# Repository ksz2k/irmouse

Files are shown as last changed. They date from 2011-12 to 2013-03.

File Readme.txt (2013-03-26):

Readme for IRMouse - infra red controlled USB mouse device (HID class)

https://github.com/ksz2k/irmouse

	ABOUT IRMouse

IRMouse is an USB mouse controlled by ir remote..
It receives packets from remote, decodes, and (if ir code matching) sends 
reports to PC via USB.. Reports are as in standard USB mouse, so there is no
need for additional programs/drivers on PC side, everything is done in IRMouse
and system recognizes it as standard USB mouse..

It is built on two ATtiny2313 uC's connected via USART..
I've tried to make it on one ATmega8, but there was too much interrupts at
the same time (from USB host and from IR), and one AVR couldn't make it work,
after few packets received from remote, the device was disapeared from USB bus.
If you're more interested on this problem, see
http://forums.obdev.at/viewtopic.php?t=243  (-;

	HARDWARE / FIRMWARE MISC INFORMATION

For now firmware decodes only SPACE_ENCODED standards of IR transmittion,
if you'll add your own, let me know..

The USB ATtiny is clocked by external 12MHz crystal, IR ATtiny by internal 
8MHz clock.

Aditionally I've used some strange Sanyo remote, that for every ir packet was 
sending different code, and only first was always the same, so there is an 
option for check only first code, and send reports without later ir code 
recheck. This happens when JP1 is closed to GND..

	PRE-BUILD CONFIGURATION

You probably want to change the remote codes and timings, I'm using separate .h
file for every remote, in remotes/ there is remote_template.h as template, just
rename it to yours remote and define it's timings and codes. Then change
REMOTE in Makefile and add #ifdef in main-ir.c

If ZERO_TEST in main-ir.c is defined, device comparing the TZEROH time, else 
TONEH. You may need to compare other times, you can change it in main-ir.c in 
main() and makeReport() functions..

In usbconfig.h you can change the device/vendor names, but be careful, because
the compilers' output file for USB is 2036B size, so it's almost full..

USART speed is 38400bd, it can be changed in defines.h

	BUILD INFORMATION

The firmware code was written for and tested with avr-gcc (avr-libc 1.4), 
compiled on Linux, but with WinAVR on Windows should work fine too.. For 
programming the AVR's I've used great AVRDUDE.. See Makefile for info and some
config options..

To build firmware, just 'make' and there should be two .hex files.. 
'make flashir' flashes the IR target, and 'make flashusb' - USB target. 
Also you can set fuses of both targets ('make fuseir' and 'make fuseusb'). 
For more details see Makefile's comments..

	LICENSE

The project is built with AVR USB driver by Objective Development, which is
published under a proprietary Open Source license. To conform with this
license, IRMouse is distributed under the same license conditions. See the
file usbdrv/License.txt for details. 

	FILES IN THE DISTRIBUTION

Readme.txt ............. The file you are currently reading
usbdrv ................. AVR USB driver by Objective Development
usbdrv/License.txt ..... Public license for AVR USB driver and IRMouse
circuit ................ Circuit diagram in PNG and EAGLE format
remotes ................ Different remotes header files
main-ir.c .............. Main file for IR ATtiny
main-usb.c ............. Main file for USB ATtiny
usbconfig.h ............ USB configuration file
defines.h .............. Some definitions for both IR and USB uC's

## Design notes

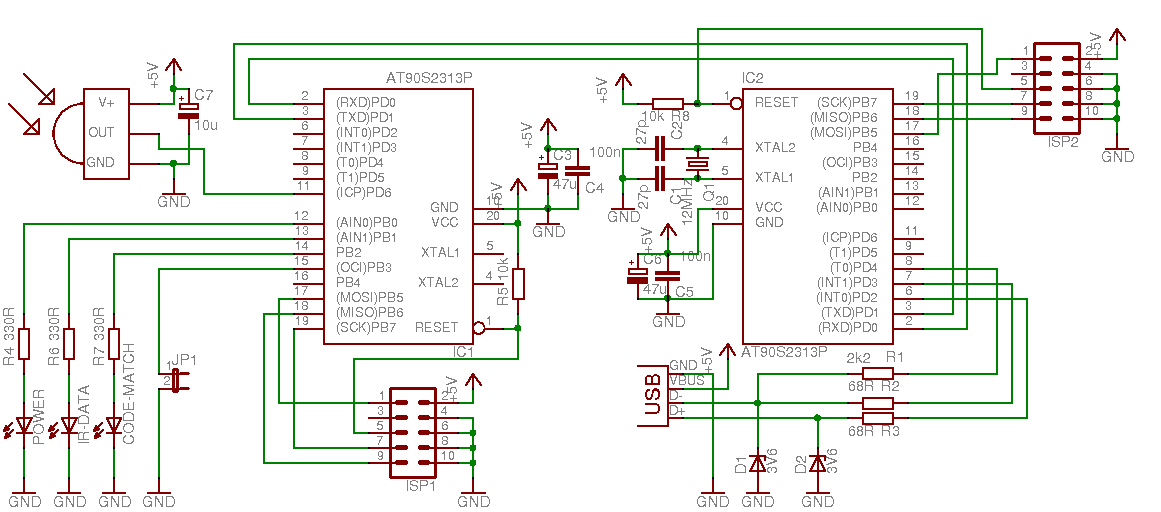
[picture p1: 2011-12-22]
circuit/irmouse.png

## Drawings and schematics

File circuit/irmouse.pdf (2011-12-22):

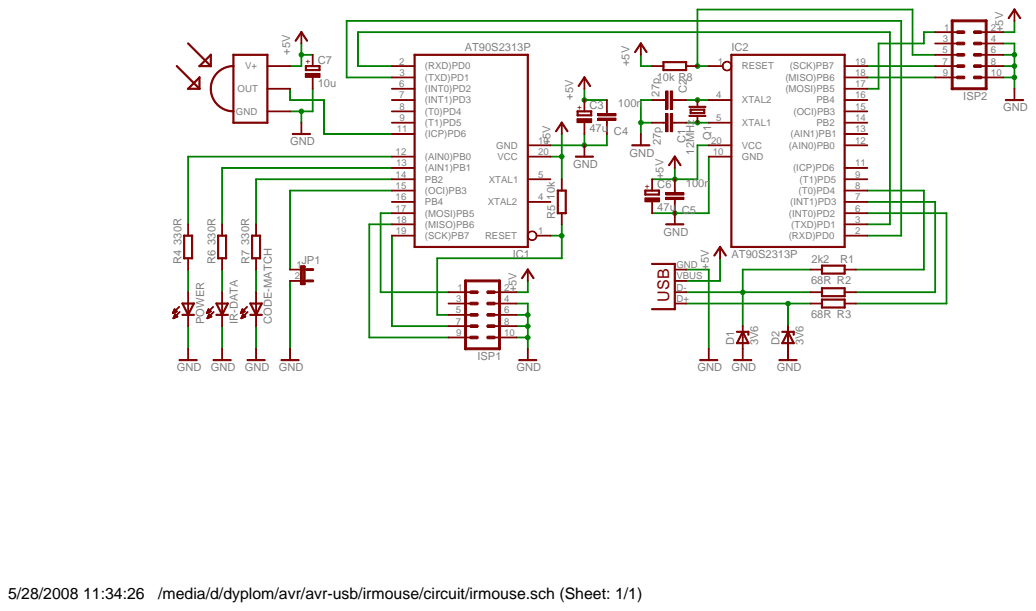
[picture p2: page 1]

5/28/2008 11:34:26 /media/d/dyplom/avr/avr-usb/irmouse/circuit/irmouse.sch (Sheet: 1/1)

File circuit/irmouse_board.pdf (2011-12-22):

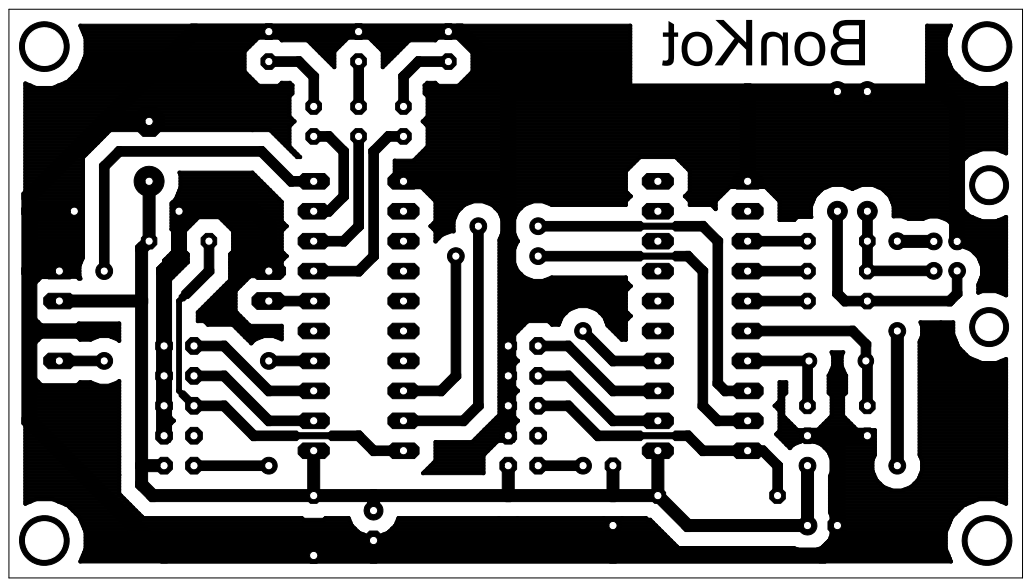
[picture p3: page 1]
t oKnoB

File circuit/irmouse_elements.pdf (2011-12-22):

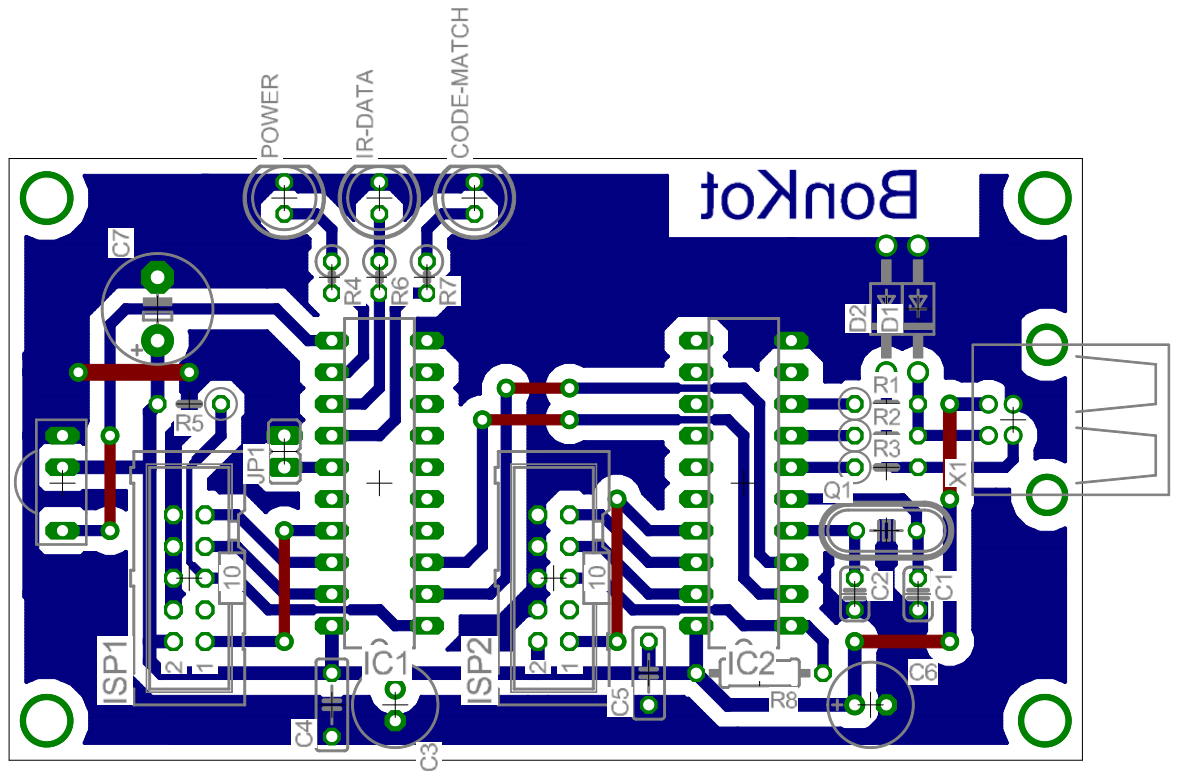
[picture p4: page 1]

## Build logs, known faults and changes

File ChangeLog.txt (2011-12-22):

2010-08-04 :: v00.21
	
	* board project added (found on the net)

2007-03-01 :: v00.20

	* remote timings and codes moved to separate files in remotes dir
	* no precompiled hex files in distribution
	* infos in Readme.txt added

2007-02-16 :: v00.10

	* first release with two tinys2313 connected via USART
	  It just works, no conflicts with host, no dmesg's errors, cursor moves :D
	
2006-01-10 - 2007-02-12 :: v00.01 - 00.09

	* test releases on one mega8, didn't work :|

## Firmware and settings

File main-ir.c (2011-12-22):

#define F_CPU   8000000L // clock frequency

#include <avr/io.h>
#include <avr/interrupt.h>
//#include <avr/pgmspace.h>
#include <avr/wdt.h>
#include <inttypes.h>
#include <string.h>

//#include "defines.h"

/******************* REMOTE CONFIG ********************************************/
#ifdef PANASONIC_VEQ1141
# include "panasonic_veq1141.h"
#else
# ifdef SANYO_PLCXT10A
#  include "sanyo_plcxt10a.h"
# else		// !SANYO_PLCXT10A
#  error "No remote type defined!!!"
# endif		// SANYO_PLCXT10A
#endif		// PANASONIC_VEQ1141

#define ZERO_TEST


/******************* PINOUT CONFIG ********************************************/
#define LED_PIN		PINB	// LED PIN
#define LED_DDR		DDRB	// LED DDR
#define LED_PORT	PORTB	// LED PORT
#define LED_PWR		0		// zasilanie
#define LED_PWR_ON	do { LED_PORT |= _BV(LED_PWR); } while(0)
#define LED_PWR_OFF	do { LED_PORT &= ~_BV(LED_PWR); }  while(0)
#define LED_IR		1		// odbior w podczerwieni
#define LED_IR_ON	do { LED_PORT |= _BV(LED_IR); }  while(0)
#define LED_IR_OFF	do { LED_PORT &= ~_BV(LED_IR); }   while(0)
#define LED_C		2		// kod przycisku pasuje do zdefiniowanych
#define LED_C_ON	do { LED_PORT |= _BV(LED_C); }  while(0)
#define LED_C_OFF	do { LED_PORT &= ~_BV(LED_C); }   while(0)
#define LED_MASK	(_BV(LED_IR) | _BV(LED_PWR) | _BV(LED_C))

// jumper okreslania sposobu sprawdzania pakietow (zwarty -sprawdza tylko pierwszy pakiet)
#define MODE_SW_PIN	PINB
#define MODE_SW_DDR	DDRB
#define MODE_SW_PORT PORTB
#define MODE_SW		3



/******************* MISC CONFIG **********************************************/
// szybkosc kursora (w pikselach)
#define MOVE		0x04

#define	TIMEOUT		3500	
#define	IR_MAX		96		
#define	SCALING		8		

/******************************************************************************/

#define calcIRTime(val) ((val + (1 << (SCALING-3-1))) >> (SCALING-3))

static	struct			// 
{
	unsigned char	length;
	unsigned char	count;
	unsigned char	data[IR_MAX];
}		ir;

static	unsigned char			edges;
static	unsigned int			irdelta;
static	uint32_t				lastcode = 0;
static	volatile unsigned char	flags = 0;
static	unsigned char    		reportBuffer[3] = {0}; 

#define IR_INTS_ON	do{TIMSK |= (_BV(OCIE1A) | _BV(ICIE1));} while(0)
#define IR_INTS_OFF	do{TIMSK &= ~(_BV(OCIE1A) | _BV(ICIE1));} while(0)
//#define IR_INTS_OFF	do{TIMSK = 0;}while(0)


static char makeReport(void);
static void sendReport(void);

// zmiana zbocza na ICP
ISR(TIMER1_CAPT_vect)
{
	static	unsigned int	prev;
	unsigned int			stamp;
	unsigned char			delta;

	stamp = ICR1;
	TCCR1B ^= _BV(ICES1);
	LED_IR_ON;
	
	delta = calcIRTime(stamp - prev);
	asm volatile("" : : "r"(delta) );
	
	prev  = stamp;
	// update timeout value 
	OCR1A = stamp + TIMEOUT * CYCLES_PER_US / 8;

	if ( !(flags & (FLG_IGNORE_PACKET | FLG_MAKING_REPORT)) )
	{
		ir.length = 0;
		if	( edges > 0 )
			ir.data[edges - 1] = delta;
		++edges;
	}
}


// timeout odbioru pakietu w podczerwieni
ISR(TIMER1_COMPA_vect)
{
	IR_INTS_OFF;
	LED_IR_OFF;
	
	if ( edges >= 40 &&
		!(flags & (FLG_IGNORE_PACKET | FLG_MAKING_REPORT))
		)
	{
		ir.count++;
		ir.length = edges - 1;		// nowy pakiet kompletny
		flags |= FLG_IR_RECEIVED;
	}
	edges = 0;
	flags &= ~FLG_IGNORE_PACKET;
	
	TCCR1B &= ~_BV(ICES1);
	
	
	TCNT0 = TCNT0V;
	TIMSK |= _BV(TOIE0);
	
	IR_INTS_ON;
	
}


ISR(TIMER0_OVF_vect)
{
	if( !edges ) {
		if( (ir.count > 0) && 
			( (lastcode == CLMB) || (lastcode == CRMB) ) ) {	
			// raportuj uwolnienie przycisku LMB/RMB
			reportBuffer[0] = 0;
			reportBuffer[1] = 0;
			reportBuffer[2] = 0;
	    	flags |= FLG_SENDING_REPORT;
		    sendReport();
        	flags &= ~FLG_SENDING_REPORT;
        }
		ir.count = 0;
		lastcode = 0;
	}
	TCNT0 = TCNT0V;	
	TIMSK &= ~_BV(TOIE0);
}


static char makeReport(void)
{
	unsigned char i = 0;
	unsigned char retval = 0;
	unsigned char cc = ir.length-2;
	uint32_t code = 0;	
	
	flags |= FLG_MAKING_REPORT;
	
	if( !(MODE_SW_PIN & _BV(MODE_SW)) && (ir.count > 0) )
		code = lastcode;
	else {
		for ( i = 0 ; i < 24 ; i++ ) {
			if (edges)
				flags |= FLG_IGNORE_PACKET;
		#ifdef ZERO_TEST
			if( ir.data[cc] > irdelta )
				code &= ~_BV(i);
			else
				code |= _BV(i);
		#else
			if( ir.data[cc] > irdelta )
				code |= _BV(i);
			else
				code &= ~_BV(i);
		#endif
			cc -= 2;
		}
	}
	
	flags &= ~FLG_MAKING_REPORT;	
	
	//if ( !(flags & FLG_SENDING_REPORT) ) {
		switch (code) {
			case CUPH:
				reportBuffer[0] = 1;
				reportBuffer[1] = 0;
				reportBuffer[2] = -MOVE;
				lastcode = code;
				retval = 1;
				break;
			case CDOWNH:
				reportBuffer[0] = 1;
				reportBuffer[1] = 0;
				reportBuffer[2] = MOVE;
				lastcode = code;
				retval = 1;
				break;
			case CLEFTH:
				reportBuffer[0] = 1;
				reportBuffer[1] = -MOVE;
				reportBuffer[2] = 0;
				lastcode = code;
				retval = 1;
				break;
			case CRIGHTH:
				reportBuffer[0] = 1;
				reportBuffer[1] = MOVE;
				reportBuffer[2] = 0;
				lastcode = code;
				retval = 1;
				break;
			case CUP:
				reportBuffer[0] = 0;
				reportBuffer[1] = 0;
				reportBuffer[2] = -MOVE;
				lastcode = code;
				retval = 1;
				break;
			case CDOWN:
				reportBuffer[0] = 0;
				reportBuffer[1] = 0;
				reportBuffer[2] = MOVE;
				lastcode = code;
				retval = 1;
				break;
			case CLEFT:
				reportBuffer[0] = 0;
				reportBuffer[1] = -MOVE;
				reportBuffer[2] = 0;
				lastcode = code;
				retval = 1;
				break;
			case CRIGHT:
				reportBuffer[0] = 0;
				reportBuffer[1] = MOVE;
				reportBuffer[2] = 0;
				lastcode = code;
				retval = 1;
				break;
			case CLMB:
				reportBuffer[0] = 1;
				reportBuffer[1] = 0;
				reportBuffer[2] = 0;
				lastcode = code;
				retval = 1;
				break;
			case CRMB:
				reportBuffer[0] = 2;
				reportBuffer[1] = 0;
				reportBuffer[2] = 0;
				lastcode = code;
				retval = 1;
				break;
			case CRMBH:
				reportBuffer[0] = 3;
				reportBuffer[1] = 0;
				reportBuffer[2] = 0;
				lastcode = code;
				retval = 1;
				break;
			default:
				reportBuffer[0] = 0;
				reportBuffer[1] = 0;
				reportBuffer[2] = 0;
				break;
		}
	//}
    return retval;
}


static void sendReport(void)
{
	unsigned char i;
	for ( i=0 ; i< sizeof(reportBuffer) ; i++ ) {
		while(!(UCSRA & _BV(UDRE))) ;
		UDR = reportBuffer[i];
	}
}

static void hardwareInit(void)
{
    MODE_SW_PORT |= _BV(MODE_SW);
    MODE_SW_DDR &= ~_BV(MODE_SW);

    LED_DDR |= LED_MASK;
    
    TCCR1B = _BV(ICNC1)	
	       | _BV(CS11);	

	// ir interrupts (OCIE1A, ICIE1)
	IR_INTS_ON;

	/*** UART init ***/
	// baud rate
	UBRRH = (unsigned char)(((F_CPU)/((BAUD_RATE)*16l)-1)>>8);
    UBRRL = (unsigned char) ((F_CPU)/((BAUD_RATE)*16l)-1);
	// potrzebujemy tylko tx
	UCSRB = _BV(TXEN);
	// asynchronous mode, 8N1
	UCSRC = _BV(UCSZ1) | _BV(UCSZ0);

	// Timer0 prescaler na 1024
	TCCR0B |= _BV(CS02) | _BV(CS00);
}



/* ------------------------------------------------------------------------- */

int	main(void)
{
# ifdef ZERO_TEST
	irdelta = calcIRTime(TZEROH);
# else
	irdelta = calcIRTime(TONEH);
# endif

	wdt_enable(WDTO_1S);
	hardwareInit();
	sei();
	LED_PWR_ON;
	LED_IR_OFF;
	LED_C_OFF;

	for(;;){
		wdt_reset();
		if ( (flags & FLG_IR_RECEIVED) ) {
		    if ( makeReport() ) {
				LED_C_ON;
		    	flags |= FLG_SENDING_REPORT;
			    sendReport();
	        	LED_C_OFF;
	        	ir.length = 0;				
			}
			flags &= ~( FLG_SENDING_REPORT | FLG_IR_RECEIVED );
		}
	}
	return 0;
}

/* ------------------------------------------------------------------------- */

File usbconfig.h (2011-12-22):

/* Name: usbconfig.h
 * Project: AVR USB driver
 * Author: Christian Starkjohann
 * Creation Date: 2005-04-01
 * Tabsize: 4
 * Copyright: (c) 2005 by OBJECTIVE DEVELOPMENT Software GmbH
 * License: Proprietary, free under certain conditions. See Documentation.
 * This Revision: Id: usbconfig-prototype.h 216 2006-07-14 21:51:00Z cs 
 */
/* 
 * Project: IR-Mouse
 * Tabsize: 4
 * Copyright: (c) 2007 by Krzysiek Szczuka
 * License: Proprietary, free under certain conditions. See Documentation.
 * This Revision: $Id: usbconfig.h 143 2007-02-27 19:02:57Z ksz $
 */


#ifndef __usbconfig_h_included__
#define __usbconfig_h_included__

/*
General Description:
This file is an example configuration (with inline documentation) for the USB
driver. It configures AVR-USB for an ATMega8 with USB D+ connected to Port D
bit 2 (which is also hardware interrupt 0) and USB D- to Port D bit 0. You may
wire the lines to any other port, as long as D- is on bit 0 and D+ is also
wired to INT0.
To create your own usbconfig.h file, copy this file to the directory
containing "usbdrv" (that is your project firmware source directory) and
rename it to "usbconfig.h". Then edit it accordingly.
*/

/* ---------------------------- Hardware Config ---------------------------- */

#define USB_CFG_IOPORTNAME      D
/* This is the port where the USB bus is connected. When you configure it to
 * "PORTB", the registers PORTB, PINB (=PORTB-2) and DDRB (=PORTB-1) will be
 * used.
 */
#define USB_CFG_DMINUS_BIT      3
/* This is the bit number in USB_CFG_IOPORT where the USB D- line is connected.
 * This MUST be bit 0 or 7. All other values will result in a compile error!
 */
#define USB_CFG_DPLUS_BIT       2
/* This is the bit number in USB_CFG_IOPORT where the USB D+ line is connected.
 * This may be any bit in the port. Please note that D+ must also be connected
 * to interrupt pin INT0!
 */

/* ----------------------- Optional Hardware Config ------------------------ */

 #define USB_CFG_PULLUP_IOPORTNAME   D 
/* If you connect the 1.5k pullup resistor from D- to a port pin instead of
 * V+, you can connect and disconnect the device from firmware by calling
 * the macros usbDeviceConnect() and usbDeviceDisconnect() (see usbdrv.h).
 * This constant defines the port on which the pullup resistor is connected.
 */
 #define USB_CFG_PULLUP_BIT          4 
/* This constant defines the bit number in USB_CFG_PULLUP_IOPORT (defined
 * above) where the 1.5k pullup resistor is connected. See description
 * above for details.
 */
/* #define  USB_BUFFER_SECTION         ".bss" */
/* The USB receive buffer (variable "usbRxBuf") with a length of 22 bytes
 * MUST NOT cross a 256 byte boundary. We have introduced this configuration
 * option to allow you to change the data segment where this buffer is
 * allocated. If you have problems with the default segment (start of .bss),
 * you may change this setting. See the comment in usbdrv.h for details.
 * On IAR C, the default is the TINY_Z segment (first 256 bytes). You must
 * change this default for devices which don't have RAM below 0x100.
 */

/* --------------------------- Functional Range ---------------------------- */
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

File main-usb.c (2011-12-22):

#define F_CPU   12000000L

#include <avr/io.h>
#include <avr/interrupt.h>
#include <avr/pgmspace.h>
#include <avr/wdt.h>
#include <inttypes.h>

#include "usbdrv.h"


static	unsigned char volatile	flags = 0;
static	uchar    				reportBuffer[3];    

#include "defines.h"


ISR(USART_RX_vect)
{
	static unsigned char bc = 0;
	
	reportBuffer[bc++] = UDR;
	
	if( (bc%3) == 0 ) {
		flags |= FLG_IR_RECEIVED;
		bc = 0;
		UCSRB &= ~_BV(RXCIE);
	}
}



static void hardwareInit(void)
{
uchar	i, j;
    
    PORTD = 0xe3;   
    DDRD = 0x1c;  
	j = 0;
	while(--j){
		i = 0;
		while(--i); 
	}
    DDRD = 0x10;   
    
    /*** UART init ***/
	// baud rate
	UBRRH = (unsigned char)(((F_CPU)/((BAUD_RATE)*16l)-1)>>8);
    UBRRL = (unsigned char) ((F_CPU)/((BAUD_RATE)*16l)-1);
	UCSRB = _BV(RXEN) | _BV(RXCIE);
	// asynchronous mode, 8N1
	UCSRC = _BV(UCSZ1) | _BV(UCSZ0);
}



/* ------------------------------------------------------------------------- */
/* ----------------------------- USB interface ----------------------------- */
/* ------------------------------------------------------------------------- */


// deskryptor USB
char usbHidReportDescriptor[] = {
    0x05, 0x01,                    // USAGE_PAGE (Generic Desktop)
    0x09, 0x02,                    // USAGE (Mouse)
    0xa1, 0x01,                    // COLLECTION (Application)
    0x09, 0x01,                    //   USAGE (Pointer)
    0xa1, 0x00,                    //   COLLECTION (Physical)
    0x05, 0x09,                    //     USAGE_PAGE (Button)
    0x19, 0x01,                    //     USAGE_MINIMUM (Button 1)
    0x29, 0x03,                    //     USAGE_MAXIMUM (Button 3)
    0x15, 0x00,                    //     LOGICAL_MINIMUM (0)
    0x25, 0x01,                    //     LOGICAL_MAXIMUM (1)
    0x95, 0x03,                    //     REPORT_COUNT (3)
    0x75, 0x01,                    //     REPORT_SIZE (1)
    0x81, 0x02,                    //     INPUT (Data,Var,Abs)
    0x95, 0x01,                    //     REPORT_COUNT (1)
    0x75, 0x05,                    //     REPORT_SIZE (5)
    0x81, 0x03,                    //     INPUT (Cnst,Var,Abs)
    0x05, 0x01,                    //     USAGE_PAGE (Generic Desktop)
    0x09, 0x30,                    //     USAGE (X)
    0x09, 0x31,                    //     USAGE (Y)
    0x15, 0x81,                    //     LOGICAL_MINIMUM (-127)
    0x25, 0x7f,                    //     LOGICAL_MAXIMUM (127)
    0x75, 0x08,                    //     REPORT_SIZE (8)
    0x95, 0x02,                    //     REPORT_COUNT (2)
    0x81, 0x06,                    //     INPUT (Data,Var,Rel)
    0xc0,                          //   END_COLLECTION
    0xc0                           // END_COLLECTION
};

uchar	usbFunctionSetup(uchar data[8])
{
usbRequest_t    *rq = (void *)data;

    usbMsgPtr = reportBuffer;
    if((rq->bmRequestType & USBRQ_TYPE_MASK) == USBRQ_TYPE_CLASS){ 
        if(rq->bRequest == USBRQ_HID_GET_REPORT){  
            return sizeof(reportBuffer);
        }
    }else{
        /* no vendor specific requests implemented */
    }
	return 0;
}


/* ------------------------------------------------------------------------- */

int	main(void)
{
	wdt_enable(WDTO_2S);
	hardwareInit();
	usbInit();
	usbDeviceConnect();
	sei();

	for(;;){
		wdt_reset();
		usbPoll();
		if (flags & FLG_IR_RECEIVED) {
			if (usbInterruptIsReady()){
            	usbSetInterrupt(reportBuffer, sizeof(reportBuffer));
            }
           	flags &= ~FLG_IR_RECEIVED;
            UCSRB |= _BV(RXCIE);
		}
	}
	return 0;
}

/* ------------------------------------------------------------------------- */

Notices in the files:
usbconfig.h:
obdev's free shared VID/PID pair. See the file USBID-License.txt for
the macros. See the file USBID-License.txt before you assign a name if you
